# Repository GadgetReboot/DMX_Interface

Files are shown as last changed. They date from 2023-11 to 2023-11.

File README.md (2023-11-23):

# DMX_Interface
DMX  RS485 to TTL isolated interface
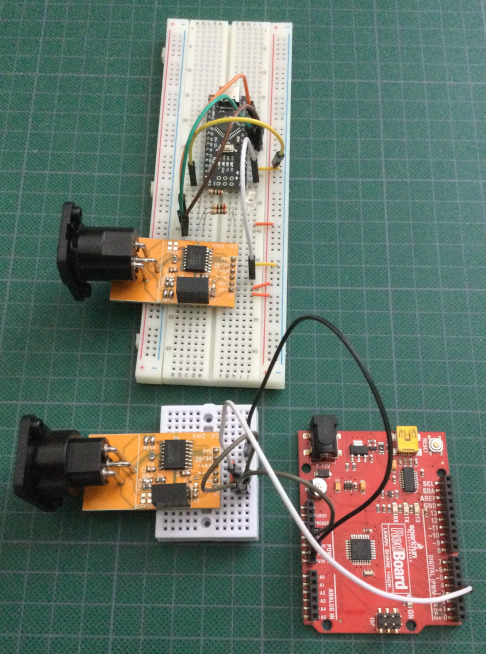
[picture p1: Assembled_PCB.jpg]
PCB
<br><br><BR><BR>
The XLR connectors used in the prototype are from Ali Express with part numbers C1019 and C1020 but it can be awkward to search for it on there.   Using a search engine and searching for "C1019 C1020 XLR 3 pin"  may show some Ali Express results that work better than searching directly on the site.

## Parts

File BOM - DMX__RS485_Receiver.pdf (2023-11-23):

DMX Receiver BOM

Item # | Reference Designator | Qty | Manufacturer | Mfg Part # | Description / Value | Package/Footprint | Type | Instructions / Notes
1 | C1 C2 C3 | 3 | Samsung | CL21B104KBCNNWC | Capacitor MLCC 100nF ±10% 50V X7R 0805 | 0805 | SMD
2 | D1 | 1 | Wurth Elektronik | 150080VS75000 | LED SMD WL-SMCW TpVw Waterclr 0805 BrtGrn | 0805 | SMD
3 | J3 | 1 | Sullins | PREC002SAAN-RC | Connector Header Through Hole 2 position 0.1" | 2POS | THRU-HOLE
4 | J1 | 1 | Sullins | PREC006SAAN-RC | Connector Header Through Hole 6 position 0.1" | 6POS | THRU-HOLE
5 | J2 | 1 | HOOYA | DIN318 | XLR male socket -20℃~+70℃ Plugin Circular Connector | 3POS | THRU-HOLE
6 | R5 R6 | 0 | | | | 0805 | SMD | Do Not Install
7 | R7 | 1 | Panasonic | ERJ-6GEYJ121V | RES SMD 120 OHM 5% 1/8W 0805 | 0805 | SMD
8 | R2 R8 | 2 | Panasonic | ERJ-6GEYJ511V | RES SMD 510 OHM 5% 1/8W 0805 | 0805 | SMD
9 | R1 | 1 | Panasonic | ERJ-6GEYJ102V | RES SMD 1K OHM 5% 1/8W 0805 | 0805 | SMD
10 | R9 | 1 | Panasonic | ERJ-6GEYJ103V | RES SMD 10K OHM 5% 1/8W 0805 | 0805 | SMD
11 | R3 R4 | 2 | Panasonic | ERJ-6GEY0R00V | RES SMD 0 OHM JUMPER 1/8W 0805 | 0805 | SMD
12 | U2 | 1 | Analog Devices | ADM2483BRWZ | DGT ISO 2.5KV RS422/RS485 16SOIC | SOIC-16 | SMD
13 | U3 | 0 | | | | SOT-23 | SMD | Do Not Install
14 | U1 | 1 | Murata Power Solutions Inc. | CRE1S0505SC | Isolated DC DC Converter 1 Output 5V 200mA 4.5V - 5.5V Input | 4POS | THRU-HOLE

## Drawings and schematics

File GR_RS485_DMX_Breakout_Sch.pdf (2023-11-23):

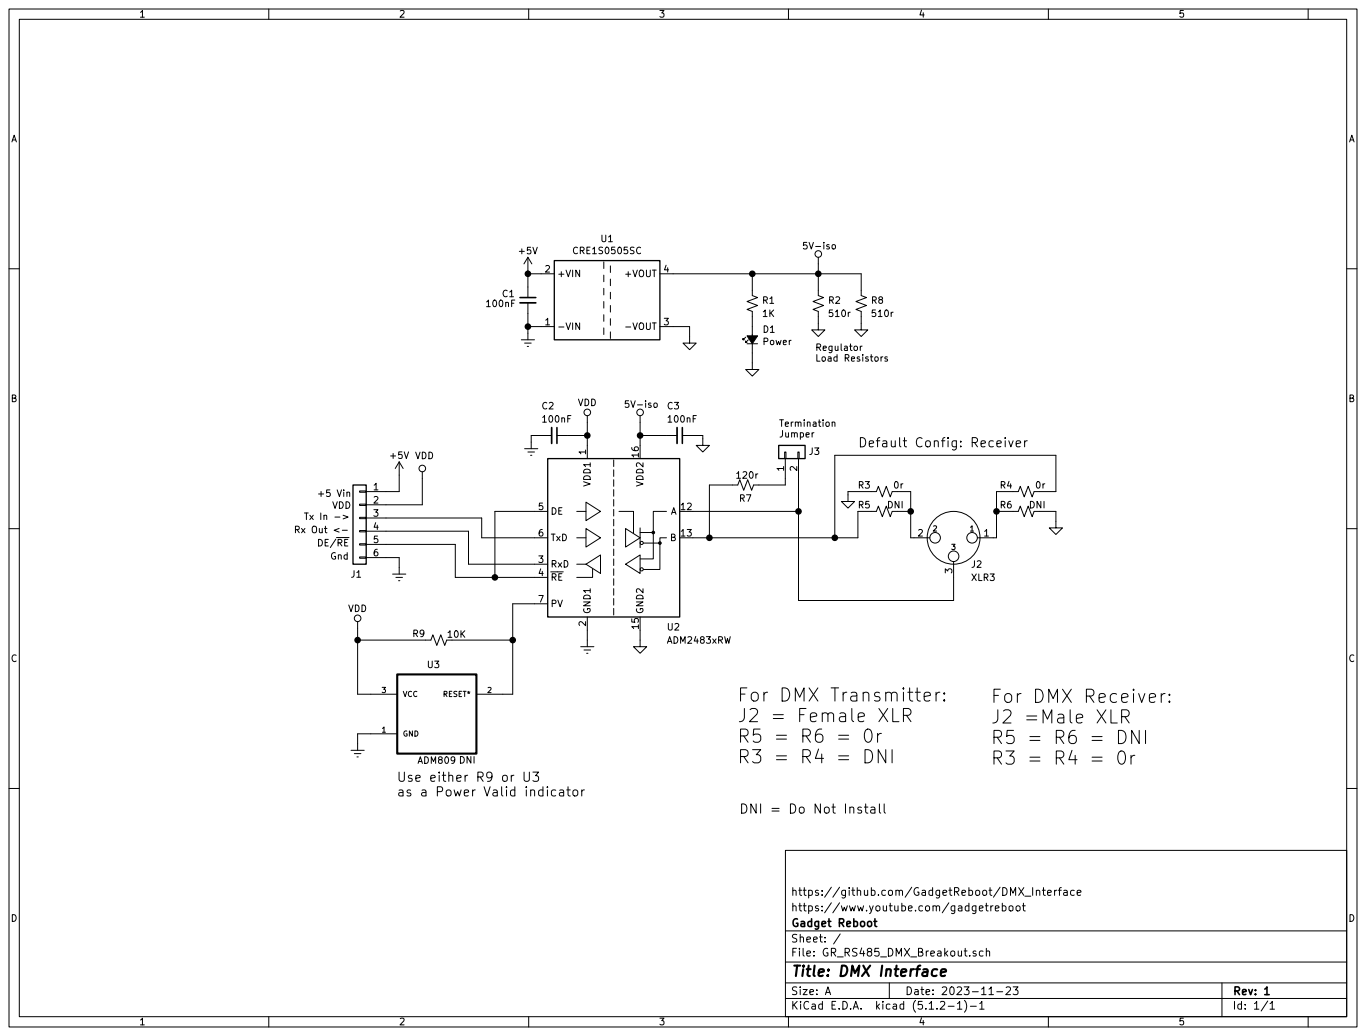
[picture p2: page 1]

510r Regulator Load Resistors 5V-iso +5V C1

2 RxD 3 RE 4 DE 5 TxD 6 PV 7 U2ADM2483xRW

as a Power Valid indicator

https://github.com/GadgetReboot/DMX_Interface
https://www.youtube.com/gadgetreboot
File: GR_RS485_DMX_Breakout.sch Sheet: / Gadget Reboot

Id: 1/1 Title: DMX Interface

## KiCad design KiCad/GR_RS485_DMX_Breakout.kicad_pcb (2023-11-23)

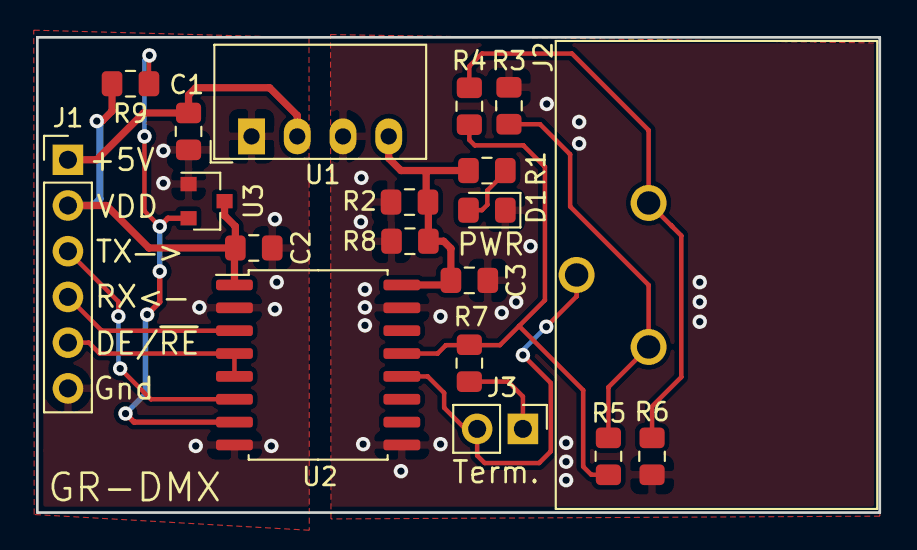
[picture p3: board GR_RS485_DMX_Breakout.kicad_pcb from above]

Board: 2 copper layers, 46.8 x 26.4 mm, 19 parts (0 on the bottom side), 15 nets.

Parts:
C1, C2, C3: 100nF; C_0805_2012Metric_Pad1.15x1.40mm_HandSolder
D1: LED_Small_ALT; LED_0805_2012Metric_Pad1.15x1.40mm_HandSolder
J1: Conn_01x06; PinHeader_1x06_P2.54mm_Vertical
J2: XLR3; DIN3_XLR
J3: Conn_01x02; PinHeader_1x02_P2.54mm_Vertical
R1: 1K; R_0805_2012Metric_Pad1.15x1.40mm_HandSolder
R2, R8: 510r; R_0805_2012Metric_Pad1.15x1.40mm_HandSolder
R3, R4: DNI; R_0805_2012Metric_Pad1.15x1.40mm_HandSolder
R5, R6: 0r; R_0805_2012Metric_Pad1.15x1.40mm_HandSolder
R7: 120r; R_0805_2012Metric_Pad1.15x1.40mm_HandSolder
R9: 10K; R_0805_2012Metric_Pad1.15x1.40mm_HandSolder
U1: CRE1S0505SC; Converter_DCDC_muRata_CRE1xxxxxxSC_THT
U2: ADM2483xRW; SOIC-16W_7.5x10.3mm_P1.27mm
U3: ADM809; SOT-23

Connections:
+5V: C1.1, J1.1, U1.2
GND: C3.1, D1.1, R2.2, R3.2, R6.1, R8.2, U1.3, U2.9, U2.15
GNDREF: C1.2, C2.2, J1.6, U1.1, U2.2, U2.8, U3.1
unnamed: D1.2, R1.2
unnamed: J1.3, U2.6
unnamed: J1.4, U2.3
unnamed: J1.5, U2.4, U2.5
unnamed: J2.1, R4.2, R6.2
unnamed: J2.2, R3.1, R5.1
unnamed: J2.3, J3.2, U2.12
unnamed: J3.1, R7.1
unnamed: R4.1, R5.2, R7.2, U2.13
unnamed: R9.1, U2.7, U3.2
VCC: C3.2, R1.1, R2.1, R8.1, U1.4, U2.16
VDD: C2.1, J1.2, R9.2, U2.1, U3.3

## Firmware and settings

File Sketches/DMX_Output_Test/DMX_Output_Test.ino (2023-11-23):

/*
   Library used:  DMX Simple https://code.google.com/archive/p/tinkerit/wikis/DmxSimple.wiki
   Hardware:      Arduino Uno

   Demo program to control 3 DMX light fixtures by individually fading red up and down on fixture 1,
   then green, blue, and white, and repeating on the next 2 fixtures before starting over.

   The fixture base addresses are 1, 5, and 9
   Each fixture has 4 channels to control R, G, B, and W
   Eg. Ch 1 = Fixture 1  Red
       Ch 2 = Fixture 1  Green
       Ch 3 = Fixture 1  Blue
       Ch 4 = Fixture 1  White
*/

#include <DmxSimple.h>

void setup() {

  /* DMX devices typically need to receive a complete set of channels
  ** even if you only need to adjust the first channel. You can
  ** easily change the number of channels sent here. If you don't
  ** do this, DmxSimple will set the maximum channel number to the
  ** highest channel you DmxSimple.write() to. */
  //DmxSimple.maxChannel(15);
  DmxSimple.usePin(3);  // DMX data output pin
}

void loop() {
  int brightness;

  // RGBW Light Fixture 1

  for (brightness = 0; brightness <= 255; brightness++) {  // fade up the brightness for fixture 1  Red (ch1)
    DmxSimple.write(1, brightness);
    delay(5);
  }
  for (brightness = 255; brightness >= 0; brightness--) {  // fade down the brightness for fixture 1  Red
    DmxSimple.write(1, brightness);
    delay(5);
  }

  for (brightness = 0; brightness <= 255; brightness++) {  // fade up the brightness for fixture 1  Green (ch2)
    DmxSimple.write(2, brightness);
    delay(5);
  }
  for (brightness = 255; brightness >= 0; brightness--) {  // fade down the brightness for fixture 1  Green
    DmxSimple.write(2, brightness);
    delay(5);
  }

  for (brightness = 0; brightness <= 255; brightness++) {  // blue
    DmxSimple.write(3, brightness);
    delay(5);
  }
  for (brightness = 255; brightness >= 0; brightness--) {
    DmxSimple.write(3, brightness);
    delay(5);
  }

  for (brightness = 0; brightness <= 255; brightness++) {  // white
    DmxSimple.write(4, brightness);
    delay(5);
  }
  for (brightness = 255; brightness >= 0; brightness--) {
    DmxSimple.write(4, brightness);
    delay(5);
  }


  // RGBW Light Fixture 2

  for (brightness = 0; brightness <= 255; brightness++) {
    DmxSimple.write(5, brightness);
    delay(5);
  }
  for (brightness = 255; brightness >= 0; brightness--) {
    DmxSimple.write(5, brightness);
    delay(5);
  }

  for (brightness = 0; brightness <= 255; brightness++) {
    DmxSimple.write(6, brightness);
    delay(5);
  }
  for (brightness = 255; brightness >= 0; brightness--) {
    DmxSimple.write(6, brightness);
    delay(5);
  }

  for (brightness = 0; brightness <= 255; brightness++) {
    DmxSimple.write(7, brightness);
    delay(5);
  }
  for (brightness = 255; brightness >= 0; brightness--) {
    DmxSimple.write(7, brightness);
    delay(5);
  }

  for (brightness = 0; brightness <= 255; brightness++) {
    DmxSimple.write(8, brightness);
    delay(5);
  }
  for (brightness = 255; brightness >= 0; brightness--) {
    DmxSimple.write(8, brightness);
    delay(5);
  }

  // RGBW Light Fixture 3

  for (brightness = 0; brightness <= 255; brightness++) {
    DmxSimple.write(9, brightness);
    delay(5);
  }
  for (brightness = 255; brightness >= 0; brightness--) {
    DmxSimple.write(9, brightness);
    delay(5);
  }

  for (brightness = 0; brightness <= 255; brightness++) {
    DmxSimple.write(10, brightness);
    delay(5);
  }
  for (brightness = 255; brightness >= 0; brightness--) {
    DmxSimple.write(10, brightness);
    delay(5);
  }

  for (brightness = 0; brightness <= 255; brightness++) {
    DmxSimple.write(11, brightness);
    delay(5);
  }
  for (brightness = 255; brightness >= 0; brightness--) {
    DmxSimple.write(11, brightness);
    delay(5);
  }

  for (brightness = 0; brightness <= 255; brightness++) {
    DmxSimple.write(12, brightness);
    delay(5);
  }
  for (brightness = 255; brightness >= 0; brightness--) {
    DmxSimple.write(12, brightness);
    delay(5);
  }

}

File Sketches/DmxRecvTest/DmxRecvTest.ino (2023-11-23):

// DMX Receiver Test
//
// Library used: DmxSerial https://github.com/mathertel/DmxSerial
// Hardware:  Arduino Nano
//
// Receives DMX data and pwm-controls a 4 pin RGB common Anode LED
// DMX address 9  controls Red
// DMX address 10 controls Green
// DMX address 11 controls Blue
// DMX address 12 controls White (sets red, green, and blue with the same data to get white)
//
// The data input pin is the serial UART Rx pin (D1) so connect the TTL data to this pin
// Be sure to disconnect the DMX data from the UART Rx pin when programming or it will
// prevent programming


#include <DMXSerial.h>

// common anode RGB led pins for pwm brightness control
const int RedPin =    9;
const int GreenPin =  6;
const int BluePin =   5;

// 255 = off for common anode
#define RedDefaultLevel   255
#define GreenDefaultLevel 255
#define BlueDefaultLevel  255

void setup () {
  DMXSerial.init(DMXReceiver);

  // set default LED rgb levels 
  analogWrite(RedPin,   RedDefaultLevel);
  analogWrite(GreenPin, GreenDefaultLevel);
  analogWrite(BluePin,  BlueDefaultLevel);

  pinMode(RedPin,   OUTPUT);
  pinMode(GreenPin, OUTPUT);
  pinMode(BluePin,  OUTPUT);
}


void loop() {

  // if DMX data has been received for channel 9 through 12, control the LED
  // the pwm value used is 255 minus received data value because for common anode, 
  // the LED is on when the control data is 0 and off when data is 255.
  if (DMXSerial.read(12) > 0) {
    // treat the RGB LED as a white LED if the white level is > 0 (set RGB channels to the same brightness to get white)
    analogWrite(RedPin,   255 - DMXSerial.read(12));
    analogWrite(GreenPin, 255 - DMXSerial.read(12));
    analogWrite(BluePin,  255 - DMXSerial.read(12));
  }
  else {
    // read recent RGB DMX values and set pwm levels
    analogWrite(RedPin,   255 - DMXSerial.read(9));
    analogWrite(GreenPin, 255 - DMXSerial.read(10));
    analogWrite(BluePin,  255 - DMXSerial.read(11));
  }
}
